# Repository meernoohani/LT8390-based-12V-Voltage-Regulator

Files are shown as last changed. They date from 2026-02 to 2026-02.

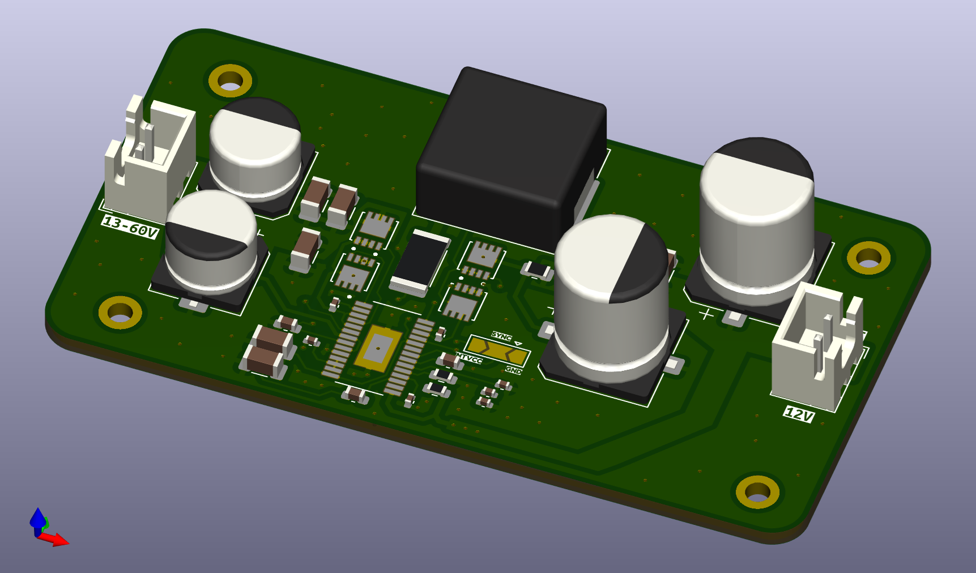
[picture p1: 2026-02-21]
Images/PCB_Front_View_2.png

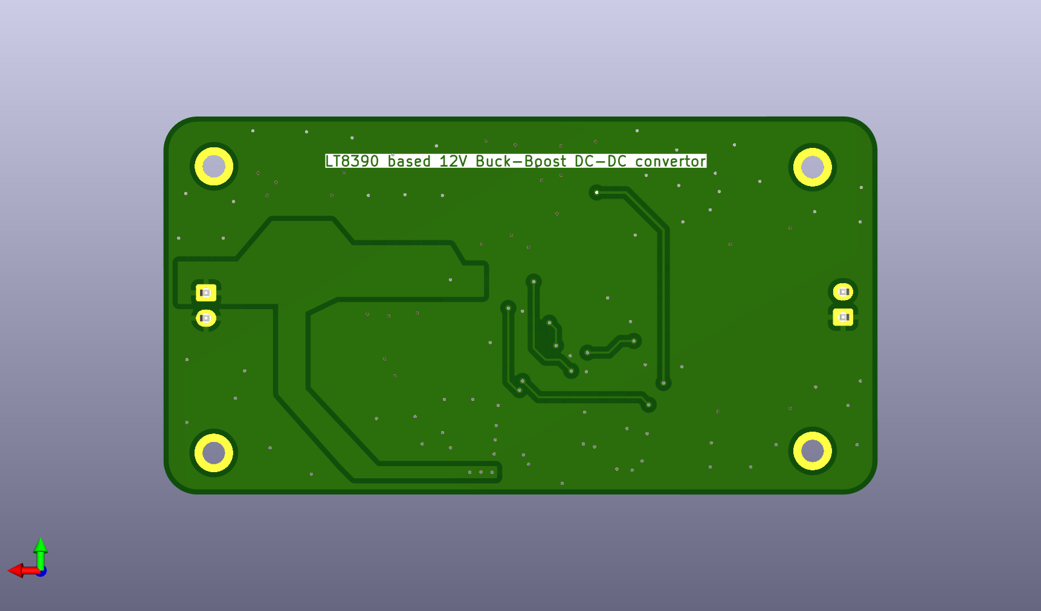
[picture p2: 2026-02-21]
Images/PCB_Back_View.png

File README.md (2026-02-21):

# LT8390 Synchronous 4-Switch Buck-Boost Converter (12V Output)

This repository contains the design files for a high-efficiency voltage regulator based on the **LT8390EFE**. The board is designed to provide a stable **12V output** from a wide input voltage range (**13V - 60V**), making it ideal for automotive, industrial, and battery-powered applications where the input voltage can be higher or lower than the desired output.

## 🛠 Features
* **Controller:** Analog Devices (Linear Tech) LT8390.
* **Topology:** Synchronous 4-switch Buck-Boost (provides seamless transitions between modes).
* **Input Voltage Range:** 13V to 60V DC.
* **Output Voltage:** Fixed 12V DC.
* **Efficiency:** High-efficiency synchronous rectification using low $R_{DS(on)}$ MOSFETs.
* **Design Tool:** Created with **KiCad 9.0**.
* **Form Factor:** Compact PCB with optimized thermal management and power paths.


## 🔌 Hardware Highlights
* **Power Stage:** Utilizes four external N-channel MOSFETs for maximum current capability and efficiency.
* **Integrated Protection:** Includes input undervoltage lockout (UVLO) and soft-start functionality.
* **Thermal Design:** Large copper pours and thermal vias are implemented to manage heat dissipation from the inductor and MOSFETs.
* **EMI Optimization:** Provision for spread spectrum frequency modulation (SSFM) to reduce EMI signatures.

## ⚙️ Technical Specifications
| Parameter | Value |
| :--- | :--- |
| **Input Voltage ($V_{IN}$)** | 13V - 60V |
| **Output Voltage ($V_{OUT}$)** | 12V |
| **Switching Frequency** | Set via RT resistor (refer to schematic) |
| **Inductor** | High-current shielded power inductor |
| **Input Capacitance** | High-voltage electrolytic + ceramic decoupling array |

## 🚀 Potential Applications
* **Automotive Power:** Stable 12V rail for electronics from a fluctuating 24V/48V vehicle bus.
* **Battery Regulation:** Maintaining 12V from a discharging high-voltage battery pack (e.g., 10S-14S Li-ion).
* **Industrial Control:** Wide-input 24V/48V DC-DC conversion for sensitive sensors.
* **Solar Power:** Regulation of variable solar panel outputs to a fixed 12V battery charging rail.

---
*Note: This project involves high-current power electronics. Ensure proper cooling and current-limit testing during initial bring-up.*

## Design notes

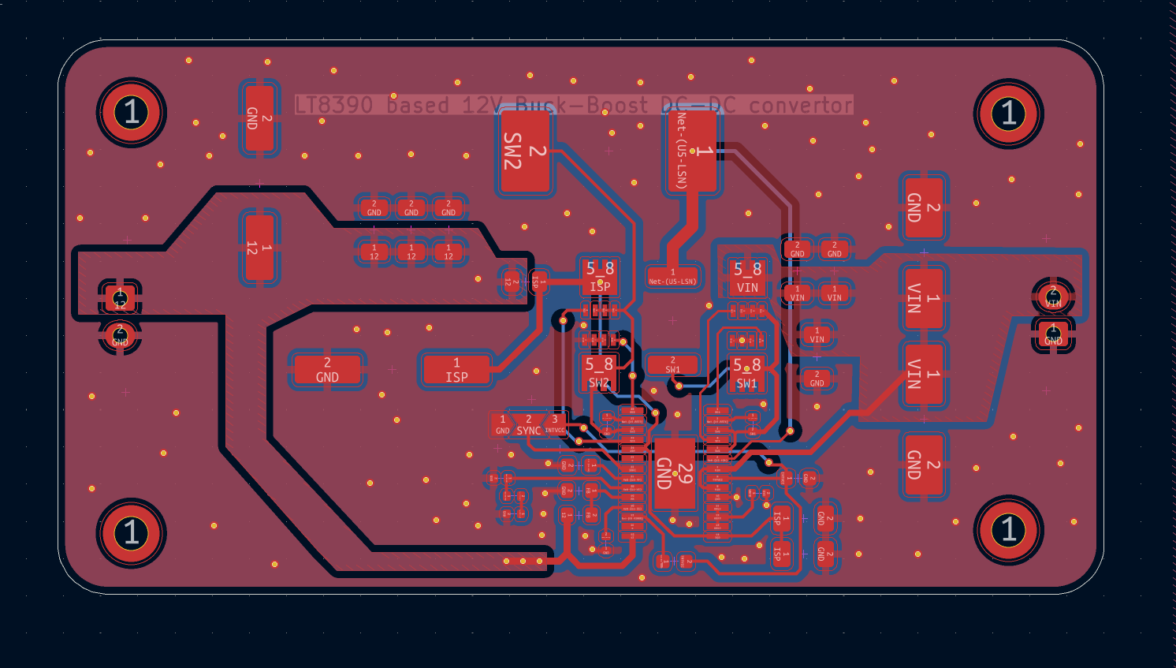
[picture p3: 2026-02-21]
Images/PCB.png

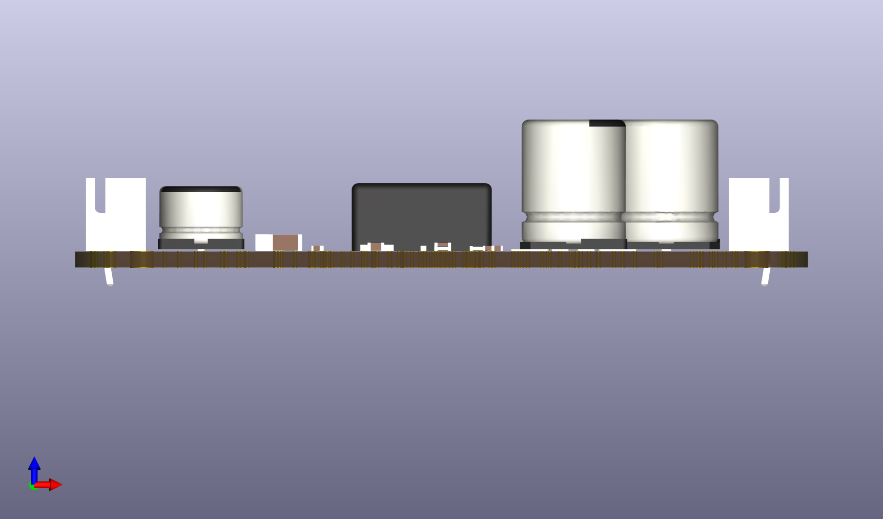
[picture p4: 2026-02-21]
Images/PCB_Side_View_2.png

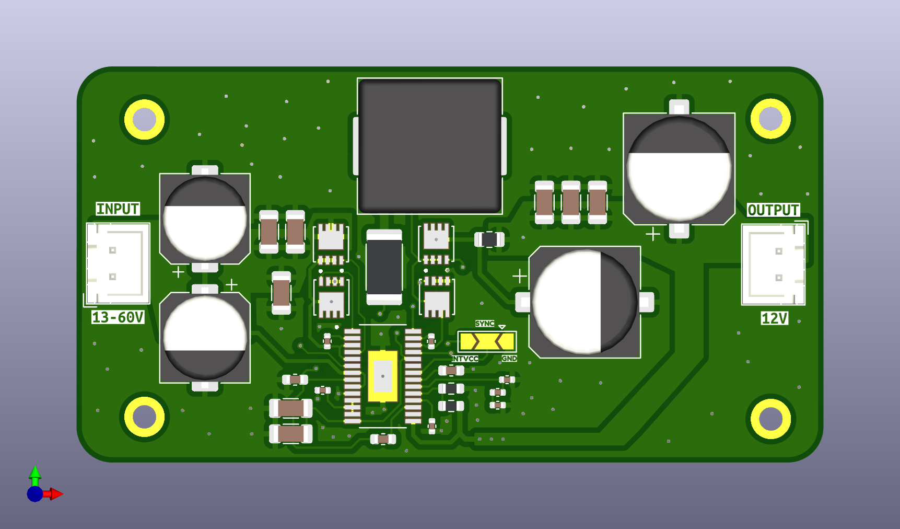
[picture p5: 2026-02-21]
Images/PCB_Front_View.png

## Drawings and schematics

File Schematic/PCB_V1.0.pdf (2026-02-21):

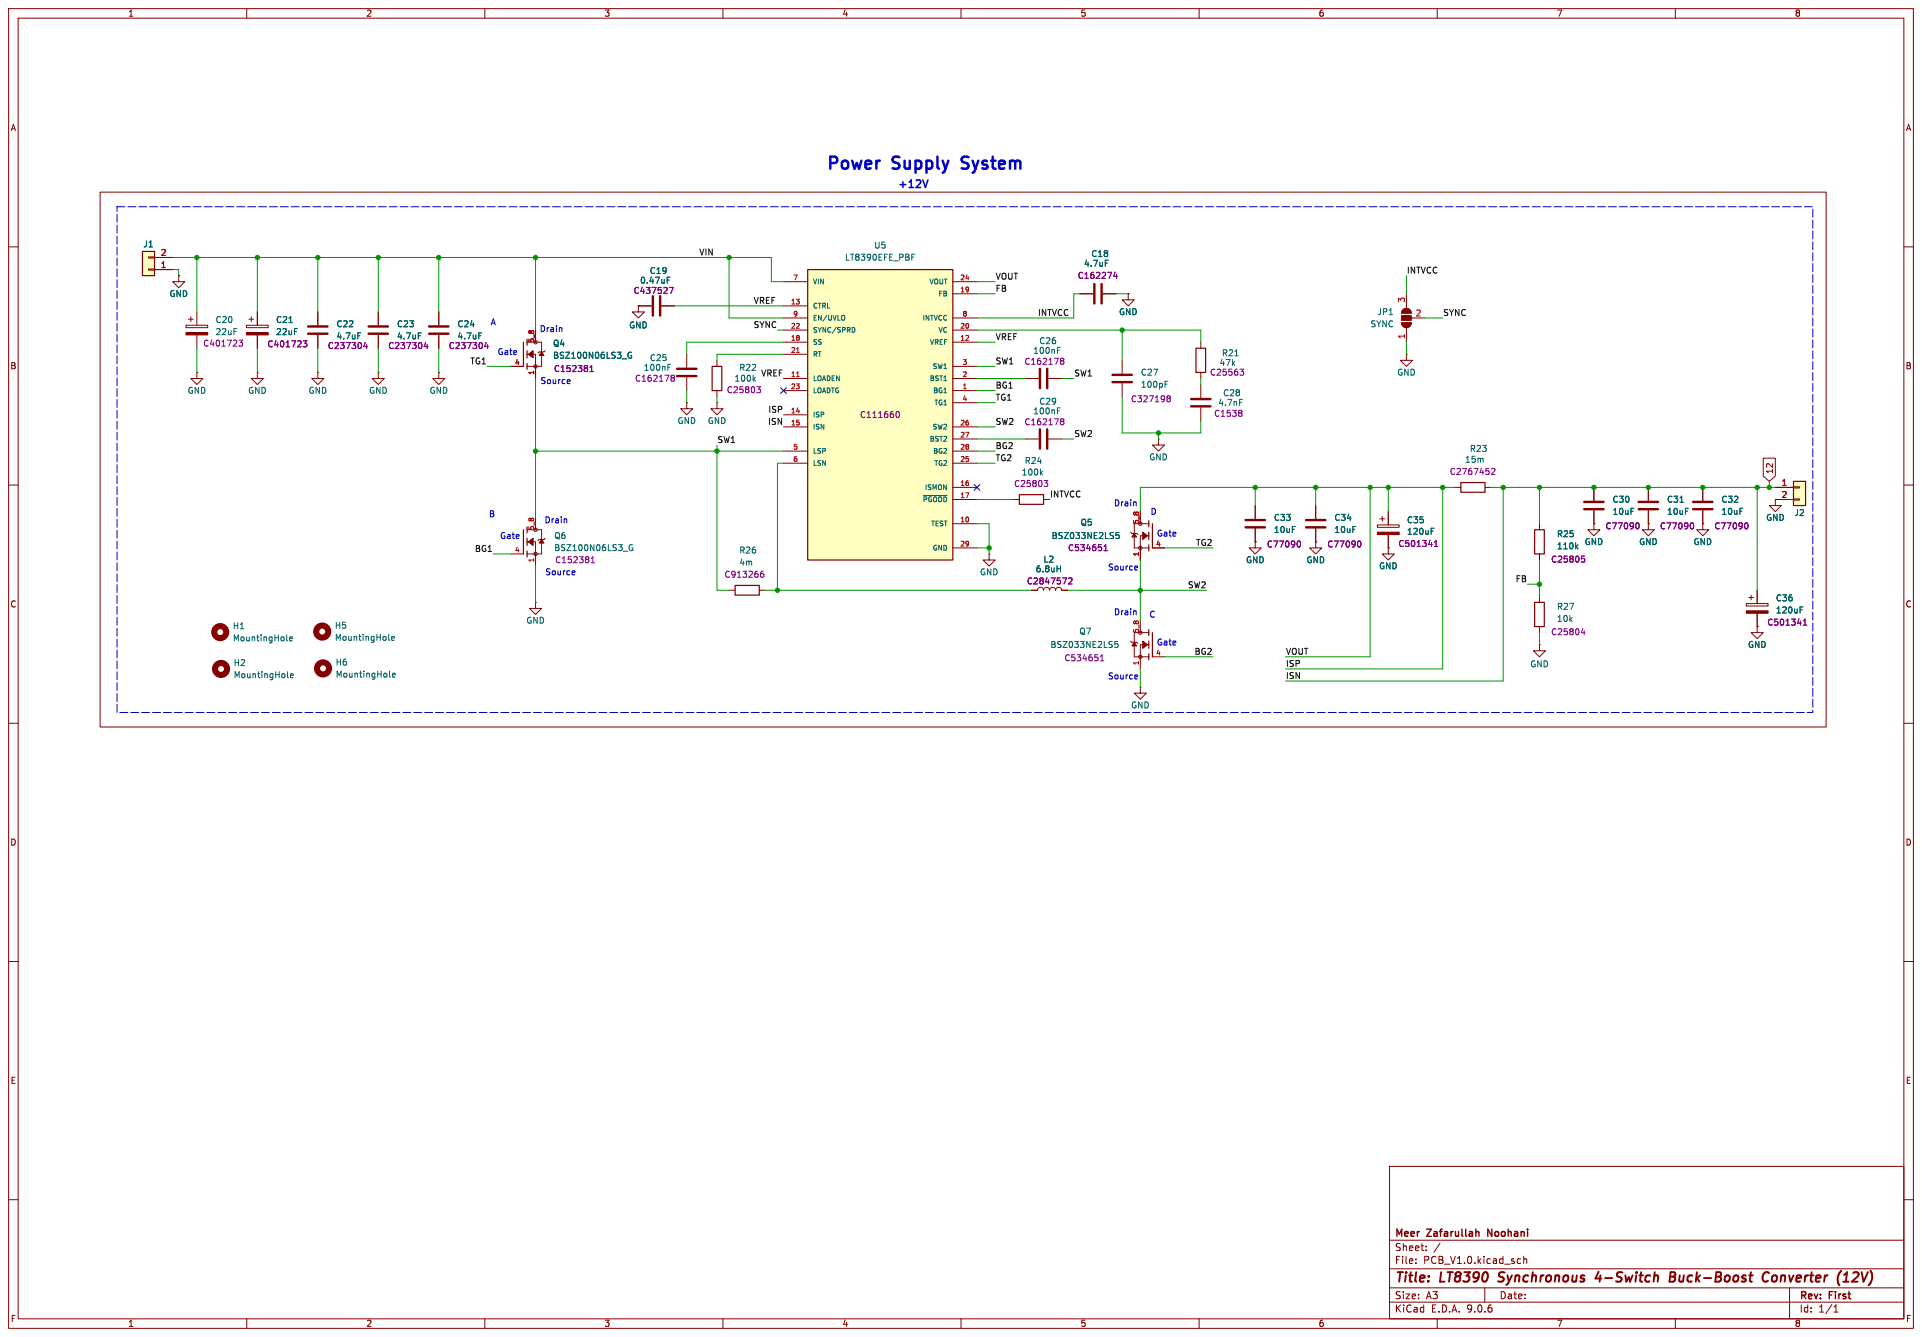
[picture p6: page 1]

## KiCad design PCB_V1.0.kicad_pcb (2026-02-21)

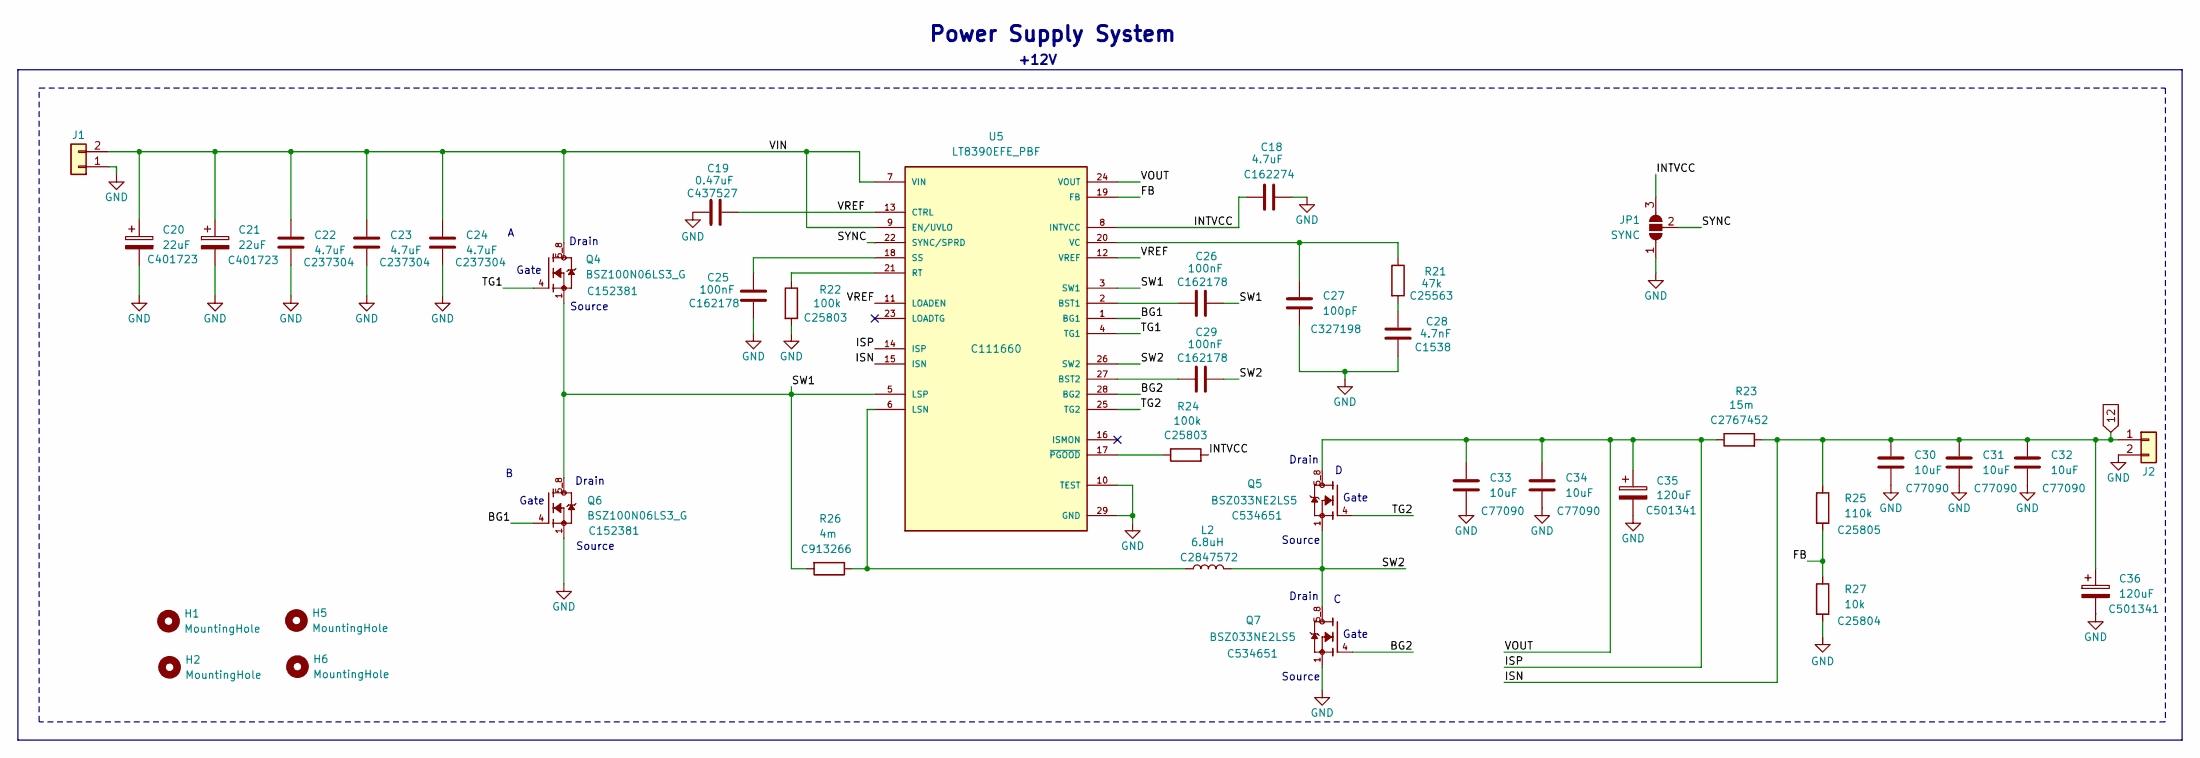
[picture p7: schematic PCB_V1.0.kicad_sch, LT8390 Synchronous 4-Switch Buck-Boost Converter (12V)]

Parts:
C18: 4.7uF; C_0603_1608Metric; LCSC C162274
C19: 0.47uF; C_0402_1005Metric; LCSC C437527
C20, C21: 22uF; CP_Elec_8x6.2; LCSC C401723
C22, C23, C24: 4.7uF; C_1206_3216Metric; LCSC C237304
C25, C26, C29: 100nF; C_0402_1005Metric; LCSC C162178
C27: 100pF; C_0402_1005Metric; LCSC C327198
C28: 4.7nF; C_0402_1005Metric; LCSC C1538
C30, C31, C32, C33, C34: 10uF; C_1206_3216Metric; LCSC C77090
C35, C36: 120uF; CP_Elec_10x12.6; LCSC C501341
H1, H2, H5, H6: MountingHole; MountingHole_2.2mm_M2_DIN965_Pad
J1, J2: Conn_01x02; JST_XH_B2B-XH-A_1x02_P2.50mm_Vertical
JP1: SYNC; SolderJumper-3_P2.0mm_Open_TrianglePad1.0x1.5mm
L2: 6.8uH; L_Sunlord_MWSA1265S; LCSC C2847572
Q4, Q6: BSZ100N06LS3_G; TRANS_BSZ100N06LS3_G; PARTREV 2.4; LCSC C152381
Q5, Q7: BSZ033NE2LS5; TRANS_BSZ100N06LS3_G; PARTREV 2.4; LCSC C534651
R21: 47k; C_0402_1005Metric; LCSC C25563
R22, R24: 100k; C_0603_1608Metric; LCSC C25803
R23: 15m; R_0805_2012Metric; LCSC C2767452
R25: 110k; R_0603_1608Metric; LCSC C25805
R26: 4m; R_2512_6332Metric; LCSC C913266
R27: 10k; R_0603_1608Metric; LCSC C25804
U5: LT8390EFE_PBF; PARTREV B; LCSC C111660

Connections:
12: C30.1, C31.1, C32.1, C36.1, J2.1, R23.2, R25.1, U5.15 (ISN)
/BG1: Q6.4, U5.1 (BG1)
/BG2: Q7.4, U5.28 (BG2)
/FB: R25.2, R27.1, U5.19 (FB)
/INTVCC: C18.1, JP1.3 (B), R24.2, U5.8 (INTVCC)
/ISP: C33.1, C34.1, C35.1, Q5.5_8, R23.1, U5.14 (ISP), U5.24 (VOUT)
/SW1: C26.2, Q4.1, Q4.2, Q4.3, Q6.5_8, R26.2, U5.3 (SW1), U5.5 (LSP)
/SW2: C29.2, L2.2, Q5.1, Q5.2, Q5.3, Q7.5_8, U5.26 (SW2)
/SYNC: JP1.2 (C), U5.22 (SYNC/SPRD)
/TG1: Q4.4, U5.4 (TG1)
/TG2: Q5.4, U5.25 (TG2)
/VIN: C20.1, C21.1, C22.1, C23.1, C24.1, J1.2, Q4.5_8, U5.7 (VIN), U5.9 (EN/UVLO)
/VREF: C19.1, U5.11 (LOADEN), U5.12 (VREF), U5.13 (CTRL)
GND: C18.2, C19.2, C20.2, C21.2, C22.2, C23.2, C24.2, C25.1, C27.2, C28.2, C30.2, C31.2, C32.2, C33.2, C34.2, C35.2, C36.2, J1.1, J2.2, JP1.1 (A), Q6.1, Q6.2, Q6.3, Q7.1, Q7.2, Q7.3, R22.2, R27.2, U5.10 (TEST), U5.29 (GND)
unnamed: C28.1, R21.2
unnamed: C26.1, U5.2 (BST1)
unnamed: C29.1, U5.27 (BST2)
unnamed: L2.1, R26.1, U5.6 (LSN)
unnamed: R22.1, U5.21 (RT)
unnamed: C25.2, U5.18 (SS)
unnamed: C27.1, R21.1, U5.20 (VC)
unnamed: R24.1, U5.17 (~PGOOD)

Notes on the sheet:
Gate
Drain
Source
+12V
Power Supply System

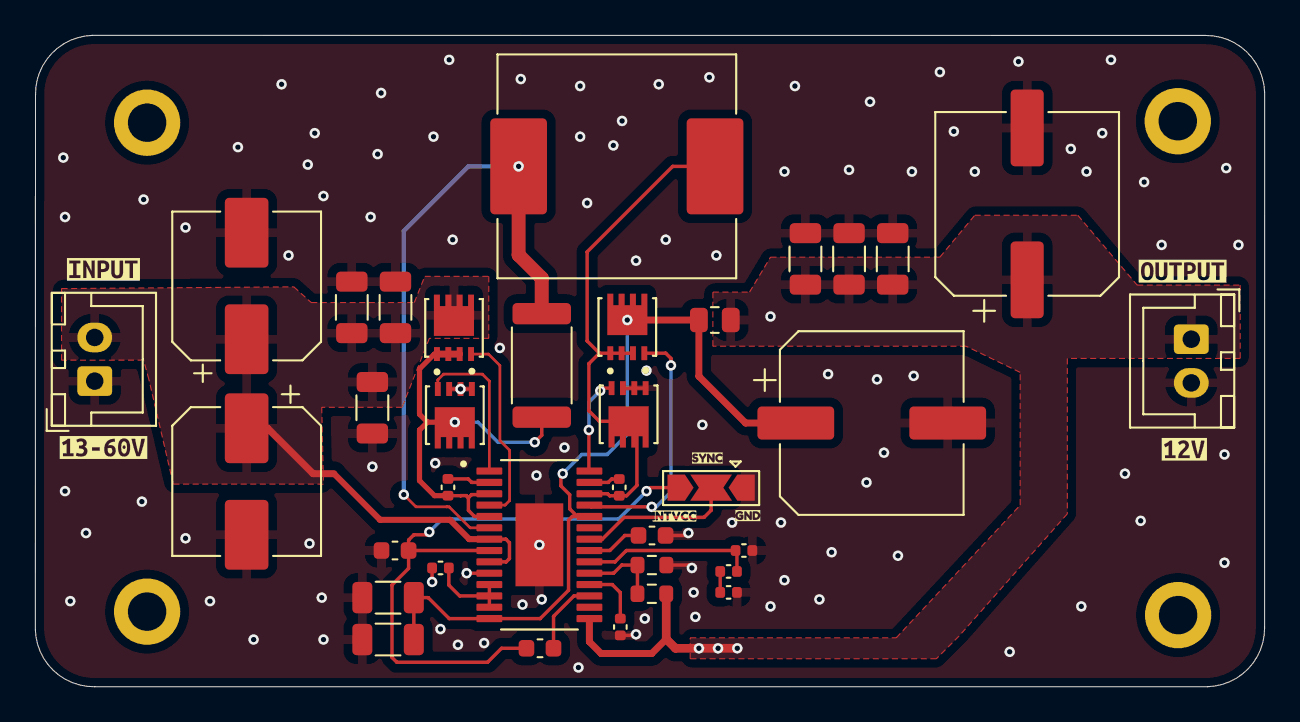
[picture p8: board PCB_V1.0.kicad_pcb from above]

Board: 2 copper layers, 70.4 x 37.3 mm, 46 parts (0 on the bottom side), 22 nets.

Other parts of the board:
kibuzzard-69945A74: G***; kibuzzard-69945A74
kibuzzard-69945B09: G***; kibuzzard-69945B09
kibuzzard-69945CB2: G***; kibuzzard-69945CB2
kibuzzard-69945CBE: G***; kibuzzard-69945CBE
kibuzzard-69945D5F: G***; kibuzzard-69945D5F
kibuzzard-69945D8C: G***; kibuzzard-69945D8C
kibuzzard-69945DBC: G***; kibuzzard-69945DBC
